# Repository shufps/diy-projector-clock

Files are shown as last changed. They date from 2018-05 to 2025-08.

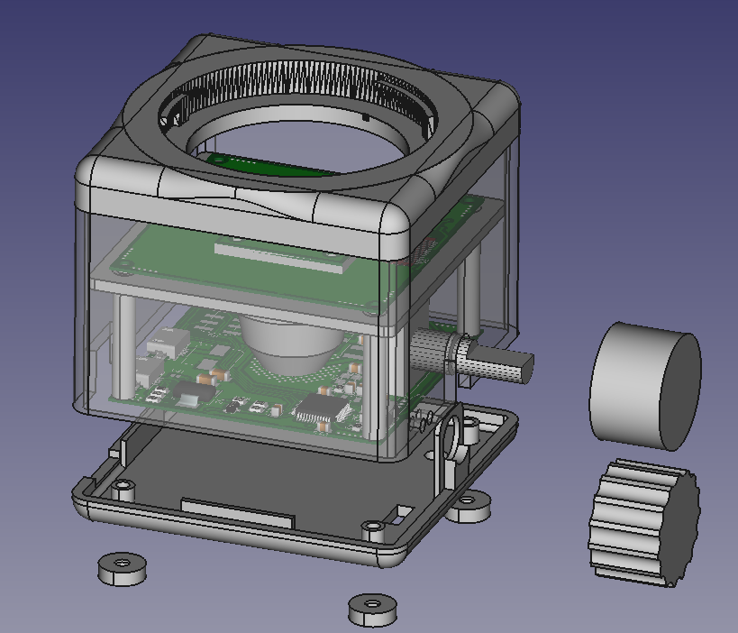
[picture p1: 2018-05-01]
images/Spectacle.Tw9321.png

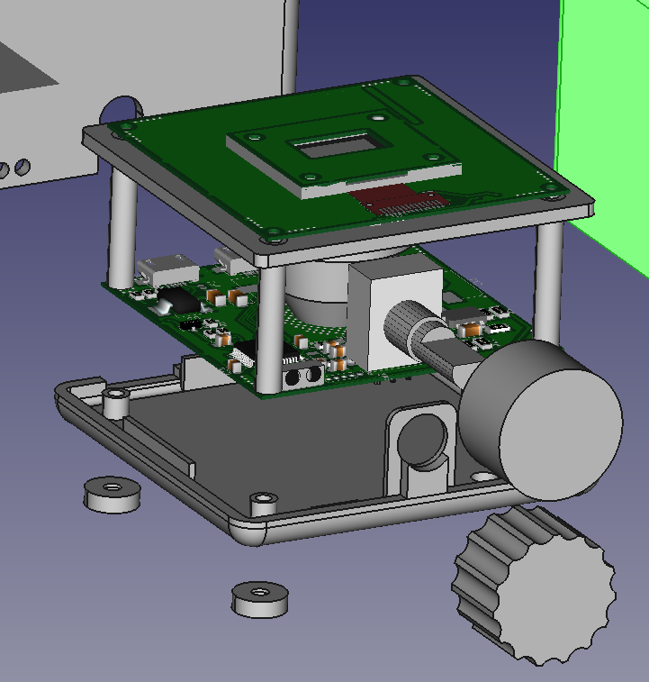
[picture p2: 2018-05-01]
stl/assembly.png

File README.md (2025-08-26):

# DIY Night Projector Clock

A Clock Projector can project the time to a ceiling in the night.



There are lots of commercial alarm clocks with integrated clock projector on the market but I thought, it would be fun to build one myself.

Moreover it was a good project for becoming accustomed to the process of 3d-designing cases which can be 3d printed and to learn about designing tolerances.

The principle is easy – basically it works like a video beamer (or any other projecting clock^^).



## LCD and Calculations
I choosed a small negative (background black) 64×32 LCD which has the dimensions of just 15mm x 12mm (active area 11.18mm x 5.58mm).



The goal was to build a complete projector with not more than 50mm x 50mm x 50mm (which I didn’t managed … But close to^^).

A small LCD has the advantage that everything becomes smaller and cheaper – this influences heavily costs for optics because a smaller LCD needs smaller optics to project an low distorted image.

Moreover a smaller LCD needs smaller focal length for a decent sized imaged on the ceiling. A good distance would be 2m from LCD to ceiling.

The formula for image width depending from the focal length is defined as:





with:
– S2 distance from lens to LCD and
– S1 distance from lens to ceiling
– W2 is the width of the LCD
– W1 is the width of the projected image

The formulas show that the smaller the focal length the larger the projected image will be.

I decided to go for 25mm because there are cheap lenses which can be obtained for about $12 in china.

For our values that would magnify the image by about x80 – 11.1mm LCD width would become 88.1cm image width on the ceiling in a distance of 2m.

## Light and Condensor Lens
It was not really clear how strong a LED has to be in order to get a reasonable well readable picture in the night on the ceiling.

To be sure – actually I wasn’t really – I decided to use a high power LED with 1W and use a cheap chinese condensor lense to parallelize the light before it passes the LCD (this has do be done anyway but a condensor lens makes it possible to use more light because condensors are shaped in a way that allowes to get the lens as near to the LED as possible – so catching more light).




The two pictures show the condensor-lense which is directly mounted to the PCB the resulting light spot on the ceiling. It is a really gread lens which is made for my LED – so it fits perfectly and parallelizes the light nicely.

## Electronics Construction
Two PCBs were designed – one holding the LCD and the actual projecting board.




The latter is equipped with 1W LED driver, STM32F103 Cortex ARM, a rotary encoder (for changing settings like brightness, standby-timer, time, …), USB, IR (both not used yet).

## Mechanics Construction
Originally, I aimed for 50mm x 50mm x 50mm but I only managed to get to 60mm x 60mm x 60mm 😥 😉

Here an overview about all I designed:



From left to right: Case with DIY projection lens (I skip this part – it worked but not really well), Sony E-Mount, C-Mount. In the middle the rest.

## LCD-Holder
A custom LCD-holder was designed to perfectly mount the LCD on the right place on the PCB.




## Case – C-Mount Variant
There are incredibly cheap chinase C-Mount lenses with a focal length of 25mm. They are sooo cheap that image quality is really really bad when using for fotography.



But surprisingly it works (almost) perfect for the Mini DIY Projector 😀



The pillow-effect (optical distortion where the edges are not straight but bent outwards) is almost neglectable – resulting a much better image than I expected (after reading reviews to this lense)



## Case – Sony E-Mount Variant
Just for fun – and because I have a 3d printer which works reliably without much attention – I did a variant for Sony E-Mount.



Here the projector with Walimex Pro 10mm 2.8 lens.



I have to admit – it isn’t that bright in reality but it’s still very readable although it is so large.



The image has more than 2m in width! And distortions almost non-existent 🙂

Downloads
GitHub-Repository contains:
– Schematic
– Layout
– Bill of material
– STM32 Cortex ARM Source
– 3D-STL-Files
– Images

Thingiverse: https://www.thingiverse.com/thing:2887852

Archive of original site: https://web.archive.org/web/20241128173803/https://microengineer.eu/2018/05/01/diy-night-clock-projector/

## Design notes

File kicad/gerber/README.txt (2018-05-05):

For best fitting, please make PCB with 0.5mm height.

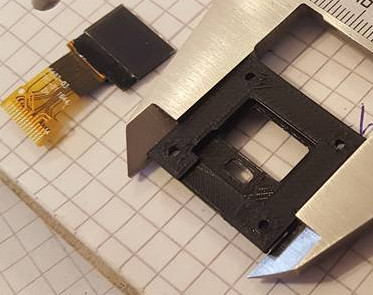
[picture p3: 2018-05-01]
images/22780314_1206666822799181_4845087505472371951_n.jpg

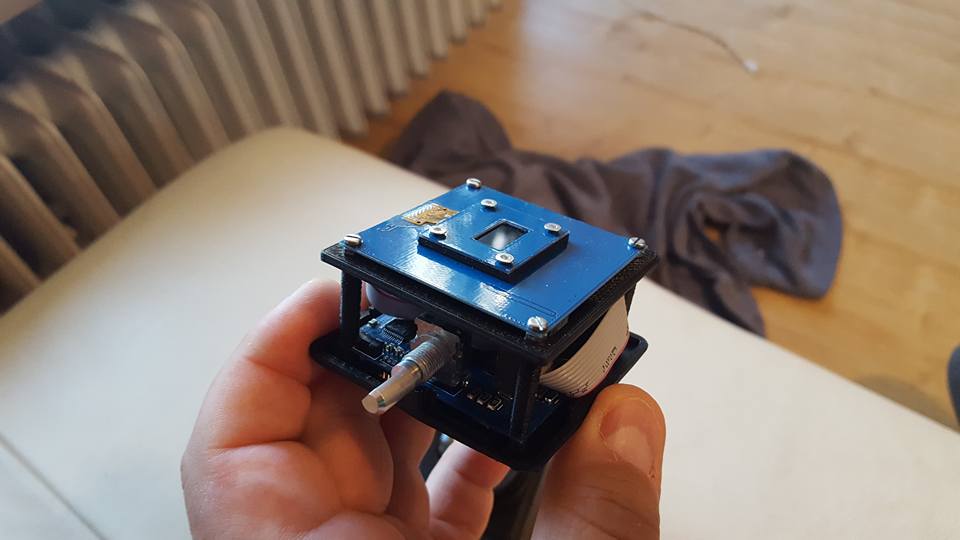
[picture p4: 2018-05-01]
images/23244059_1218023491663514_6128260922593770176_n.jpg

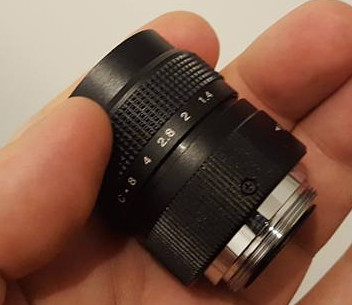
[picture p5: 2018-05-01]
images/23380257_1223416981124165_4793755427854490814_n.jpg

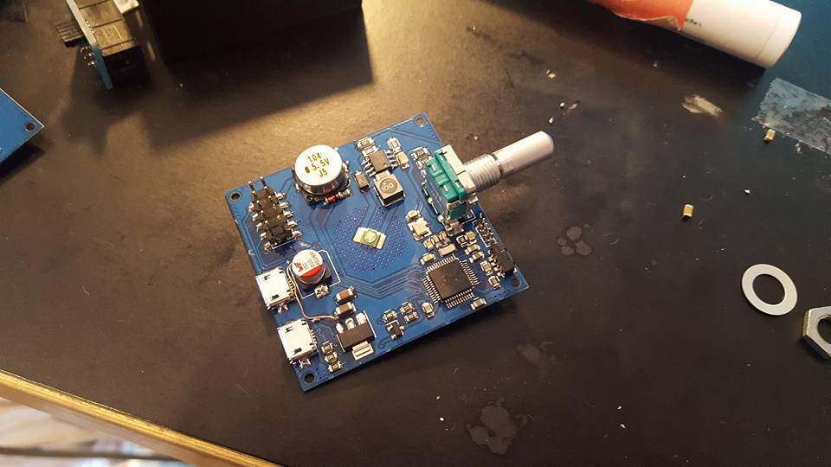
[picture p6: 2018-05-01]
images/22780624_1207215072744356_6448307703032848811_n.jpg

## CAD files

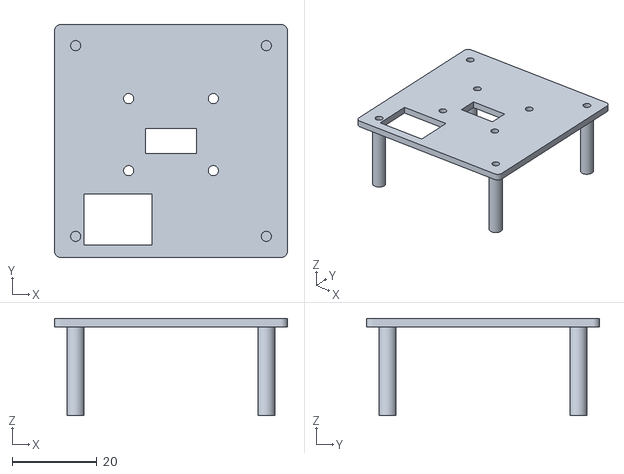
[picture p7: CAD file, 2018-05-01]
stl/spacer.stl
55.0 x 55.0 x 23.0

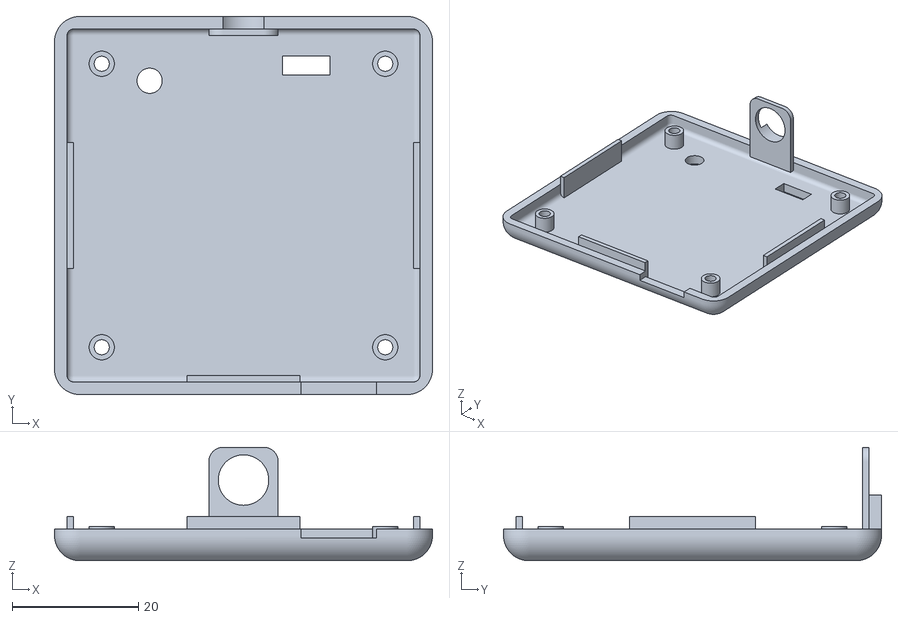
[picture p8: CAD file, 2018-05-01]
stl/case_bottom.stl
60.0 x 60.0 x 18.0

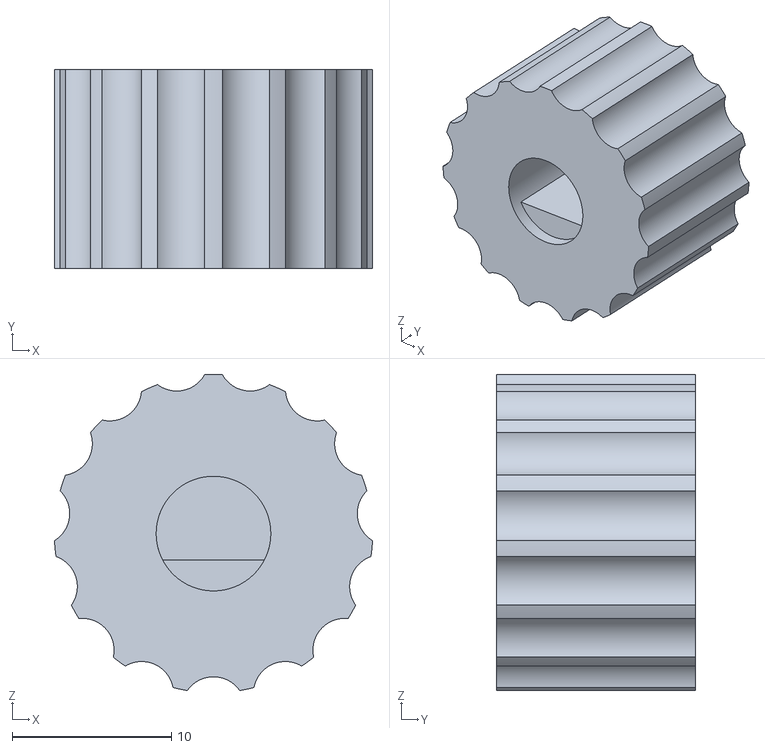
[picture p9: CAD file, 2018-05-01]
stl/know.stl
20.0 x 12.5 x 19.9

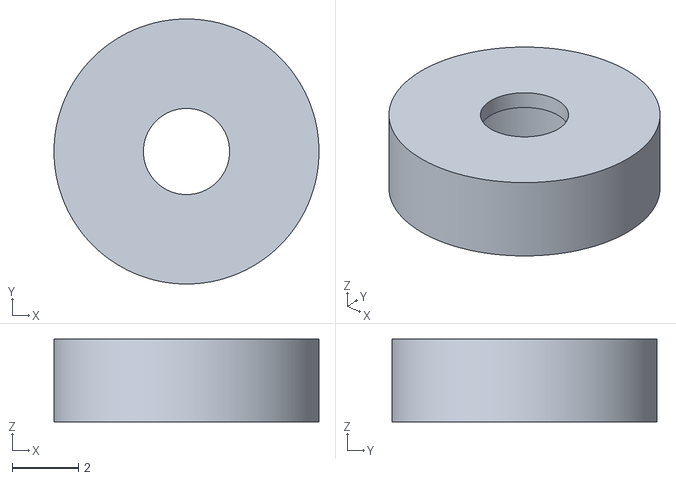
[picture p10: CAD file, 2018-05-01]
stl/case_foot.stl
8.00 x 8.00 x 2.50

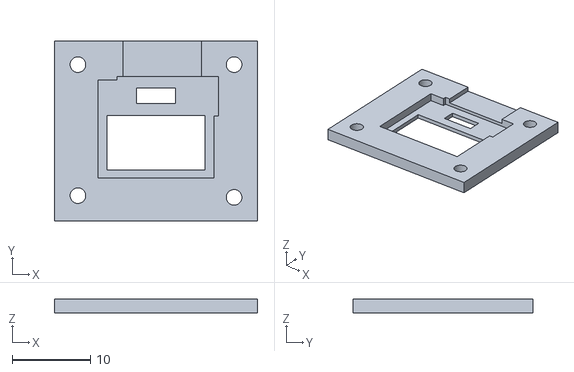
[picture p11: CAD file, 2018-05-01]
stl/lcd_holder.stl
26.0 x 23.0 x 1.80

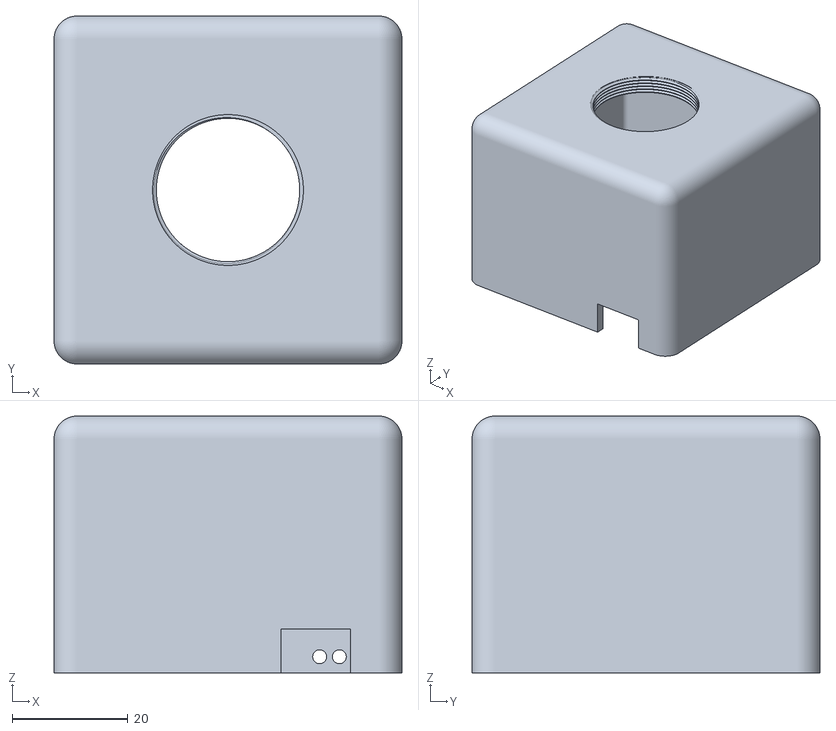
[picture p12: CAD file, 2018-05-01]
stl/case_top_cmount.stl
60.0 x 60.0 x 44.3

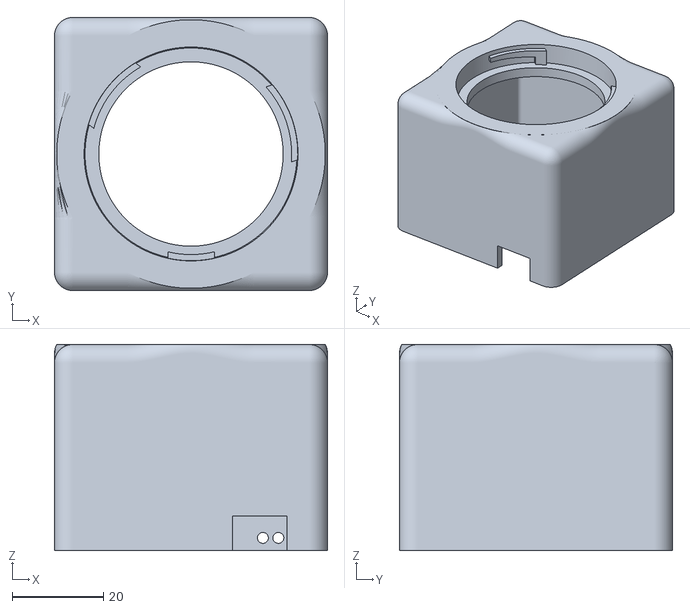
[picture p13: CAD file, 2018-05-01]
stl/case_top_emount.stl
60.0 x 60.0 x 45.3

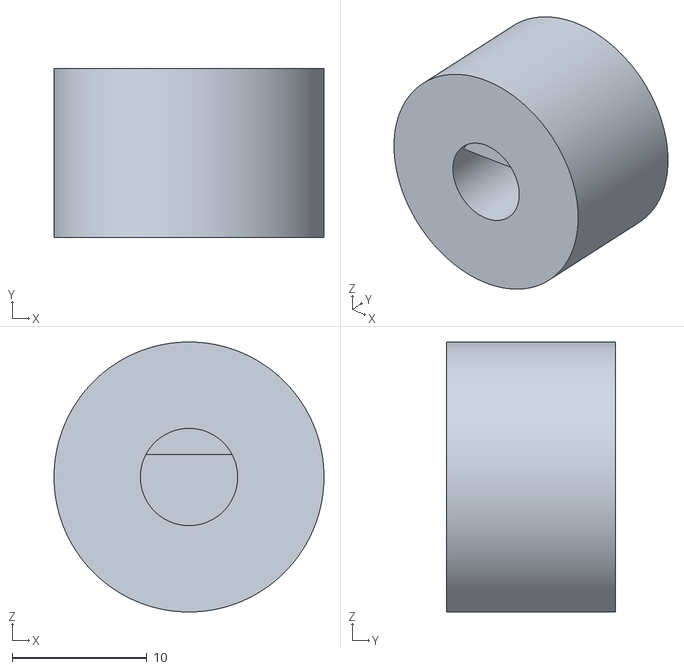
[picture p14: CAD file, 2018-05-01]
stl/knob_smooth.stl
20.0 x 12.5 x 20.0

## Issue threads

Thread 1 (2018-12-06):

Which LCD ?

spilz87, 2018-12-06:
Hello,
Very nice project, I was thinking about it for years but I didn’t find how to find the lcd.
Where did you buy the lcd ?
What’s it with backlight led that you removed ?
Thanks for your project
Regards

shufps, 2018-12-10:
Hi, sorry for answering so late ... In the repo there is a directory called "BOM" (bill of material) and in the text-file "others" there is the LCD which works:

LCD:
(search on ebay for LCD 64x32) e.g.
GLS Neu LCD-VATN 64x32 3V ST7567A I2C 15x12x2mm [LCD-AG-064032V-VIW W/KKK-E6]

shufps, 2018-12-10:
Ah forgot to answer the other question - you simply can remove without much force the backlight from the LCD :)

spilz87, 2018-12-10:
Thanks for your replies :)
I didn’t see the BOM folder ...
But there is no link to buy it.
Is there a difference with another classic RGB lcd ? (Except the size maybe)
I didn’t find your lcd on AliExpress, but I found this one :

https://www.google.fr/amp/s/m.aliexpress.com/item/32859445140.html#ampf=undefined

If I use it as “black/white” do you know if it will work or not ?
Thanks for your help

shufps, 2018-12-12:
No, OLEDs can't be used for projectors in general.

Buy this:
https://www.ebay.de/itm/GLS-Neu-LCD-VATN-64x32-3V-ST7567A-I2C-15x12x2mm-LCD-AG-064032V-VIW-W-KKK-E6/391734506852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

shufps, 2018-12-12:
Ah sorry, you are right ... Just read "OLED" at the end of the title and missed the "not" before xD
You can try, but you will have to change everything ... This would be a lot of work and would be very time consuming. If you do, I would like to keep updated, if you don't mind :)

But I don't know how good the contrast will be ... perhaps black background is milky then. This small little LCD seems to have been build for projecting applications - but of course we don't know for real.

spilz87, 2018-12-12:
The contrast could be the issue with this RGB lcd, that why I’m thinking using it only in white/black, hopping it will be enough ...

Your small lcd seems to be design to feet in key :
Q5-100-STARTER-KIT 64x32 Spi Lcd Switch & Breakout Board https://rover.ebay.com/rover/0/0/0?mpre=https%3A%2F%2Fwww.ebay.com%2Fulk%2Fitm%2F132276707938

The electronic hardware shouldn’t be a problem, I’m thinking using an ESP32 to control display, get time through internet and maybe to project small icon of weather :)

My real issue in my project was what you solved : the optical hardware

I will let you know when I will receive the components and share with you my knowledge and my project if you want

I will maybe have more questions ^^

shufps, 2018-12-12:
Niiiiice! Thank you for the link! That could be the reason why this LCD exists :-)

Looking forward hearing about your progress! :-)

spilz87, 2019-04-18:
Hello,
I’m working a lot on this project and it start to work well.
Until now I’m using the LCD 160x80 in SPI.
But I would like to have it brighter so I will test the same LCD as you.
Can you tel me more about the connection of this LCD :
Which pin of the LCD did you connect to 3.3v ? (On there are pins for dc/dc converter and one for 3.0v)
Why did you keep the led pin ?
Thanks for your help

I don’t know how to send photo of my project

shufps, 2019-04-18:
Hello,

ah yes, why did I keep the Pin for the backlight - I don't know to be honest ... The back light is removed anyways xD

I connected Pin 8 to 3.3V. You can open the schematic with KiCad.

Pilgrim182521, 2019-10-11:
Hi guys,
just started looking for LCD glass and found something like this in EU:
https://allegro.pl/oferta/art-lcd-vatn-64x32-3v-st7567a-i2c-15x12x2mm-whiten-6754828746
for some 3 Euros, shipping  included.
josef

trizmark, 2020-03-19:
Hey @shufps

Do you have a recent link to an LCD display? This is an awesome project and I'm finding it hard to locate a suitable LCD.

Thanks,
Zoltan

Pilgrim182521, 2020-03-19:
https://allegro.pl/oferta/art-lcd-vatn-64x32-3v-st7567a-i2c-15x12x2mm-whiten-6754828746
is still valid...
Josef

Pilgrim182521, 2020-03-19:
... whoops sorry, it has not been query for me... ;)

trizmark, 2020-03-19:
> ... whoops sorry, it has not been query for me... ;)

I had a look at that, but due to the current COVID-19 situation that website have stopped delivering to non-Polish addresses... :(

Appreciate the reply anyway!

AmbroAnalog, 2020-10-21:
The store Allegro.pl now seems to deliver outside Poland again, I received my shipment to Germany today.

How exactly do I get the display transparent to show through with the LED? Do I have to remove the black layer at the back?

Cthanatos, 2021-08-12:
Any chance you could provide an aliexpress link? I've tried the link above and it's in Polish, and Google's translate page feature isn't great. I've tried searching  the line from the BOM, even parts of the line but I can't seem to find what I'm looking for....

jghaanstra, 2022-01-18:
Anyone ever found a suitable replacement for the led screen in the project? I tried ordering through the Polish webshop but there is an issue with delivery and I probably lost my money. I have been unsuccesful finding a replacement.

spilz87, 2022-01-18:
If you are able to change the library you can take any lcd screen.
I'm using 0.96in tft display 80x160 with arduino based electronics and it works well

spilz87, 2022-01-18:
€ 1,69  11％ Off | 2022 New 0.96in TFT Display Module IPS Color Screen SPI For LCD 80x160 ST7735 Drive Welded Spliced Link
https://a.aliexpress.com/_vMIfpr

trizmark, 2022-01-18:
But that's not a negative LCD, right? So how would you use that for projection?

spilz87, 2022-01-18:
You have to remove the backlight

jghaanstra, 2022-01-18:
Actually just bought me the black version of [this ](https://nl.aliexpress.com/item/4000370015852.html?gatewayAdapt=glo2nld&spm=a2g0o.9042311.0.0.49714c4dHxym9T) one to try out. It comes without the backlight.

jghaanstra, 2022-01-18:
> Thanks for the link, I didn't saw it
>
> But the density of pixel is not as good, and the issue I didn't solved is a way to have an homogeneous light before the lcd screen

I assume you mean the light behind the LCD screen? Did you use some form of condensor to try and get an homogeneous light?

spilz87, 2022-01-18:
Yes the light behind the lcd screen

I tried several things but I always have something not homogeneous :(

What do you use for it ?

jghaanstra, 2022-01-18:
I just started looking into all this and I have no experience with these kind of projects. But I bought [this ](https://www.aliexpress.com/item/1W-3W-Constant-Current-LED-Driver-Warm-Natural-Cool-White-Blue-Red-Green-Yellow-LED-Chip/32984506965.html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) one as a first attempt. And I thought I just reflective tape or aluminum foil for extra spread.

spilz87, 2022-01-18:
The link does not work for me

zoltan-vonage, 2022-01-18:
> You have to remove the backlight

How hard is it to remove the backlight?

trizmark, 2022-01-18:
> You have to remove the backlight

How hard is it to remove the backlight?

jghaanstra, 2022-01-18:
> The link does not work for me

Does [this ](https://aliexpress.com/item/32984506965.html) work?

spilz87, 2022-01-18:
Yes the link works

I already tried this but it's not homogeneous and you saw it on the wall

jghaanstra, 2022-01-18:
> Yes the link works
>
> I already tried this but it's not homogeneous and you saw it on the wall

OK. what gave you the best results?

spilz87, 2022-01-18:
The best I found was a led with this :

€ 0,98 | Cree XPG lens Diameter 23.5mm (Belt holder) 5 degrees LED Lens, glass Condenser lens,
https://a.aliexpress.com/_vl5RYv

But not perfect

And as the screen is bigger, you see halo on the wall :(

catalin7, 2025-08-07:
i did my clcocprojector from a laying around clock projector. I hacked the communication to the lcd's driver with a logic analyzer, in a day i had my communication protocol established and for fun actually i have 4 display projectors , i use only 1 , my bestie. Some clocks dont have lcd driver, the lcd is connected tru a plastic conductive ribbon to the lcd. These are not good.
So my clocks are one from an Accurite, 2 from a Mesqool CR1001 i think, and another one from a LaCrosse not working clock

catalin7, 2025-08-07:
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

spilz87, 2025-08-07:
Thanks for sharing
I worked also on it and I was able to create my own one from classic lcd (no oled) by removing some back parts (not that easy, I broke some 😅)

The most difficult part is to find an homogenized light source..

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

spilz87, 2025-08-07:
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

catalin7, 2025-08-08:
or make smaller characters on a black background screen

catalin7, 2025-08-08:
this is one of my projects, it uses a projector from a clock ceiling

Closed 2018-12-10.

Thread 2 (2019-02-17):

projecting board?

jasondreher, 2019-02-17:
I can’t seem to find the board with the light on it, the project board. What did you use for this? And I assume this connects to the screen and gives it the time. I want to use this for a kitchen timer, display a countdown on the wall.

Great project, I am looking forward to trying it out!

shufps, 2019-02-28:
great idea! love it :) All board files are in the directory "kicad". The board file is named "beamer1.kicad_pcb".

Closed 2019-12-18.

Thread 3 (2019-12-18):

Clock doesn't reset to 0:00 after 23:59. It keeps counting the hours to 24, 25, 26...

SmallestLeslie, 2019-12-18:
I would like to ask for your help.
I'm trying to build the projector clock project I found here as a Chirstmas gift for my brother and I encountered some strange behavior with the firmware.
When it is in the time adjust mode it works as it should but during normal operation mode after 23:59 the date doesn't increment and the clock doesn't turn over to 0:00.
Rather it keeps incrementing the hours to 24, 25 and so on.

I would like to ask if you encountered a similar behavior and if you
have an updated firmware.

shufps, 2019-12-18:
Oh, interesting observation! :see_no_evil:

Have to admit - my girlfriend didn't want me to use the projector-clock in the bed-room, so it didn't ever run so long :/

Hmm, oh that is this silly STM32F103 microcontroller ... it really doesn't care about overflows at 24:00.

Could you retry by changing this line:
https://github.com/shufps/diy-projector-clock/blob/master/src/src/main.cpp#L233

from:
rtc_getTime24(&RTC_TimeStructure);
rtc_getDate(&RTC_DateStructure);

to:
rtc_checkUpdateDate(&RTC_TimeStructure, &RTC_DateStructure);
rtc_getTime24(&RTC_TimeStructure);
rtc_getDate(&RTC_DateStructure);

The checkUpdateDate-function also is used when reconnecting the main-power while the RTC run on battery-backup. The seconds count continuosly up. When reconnecting the clock to the main-power it has to figure out how many days have passed and it adjusts the date accordingly by calling this function.

The same has to be done for the clock not running on battery. After the RTC-counter reaches 86400 seconds, it has to be reset and the date has to be adjusted.

I hope this solves your issues :)

Btw, I would looooooove seeing a picture of your clock :heart_eyes:

shufps, 2019-12-18:
You can use the binary from this branch which has the fix:
https://github.com/shufps/diy-projector-clock/tree/24hoursbug

If it works, I'll merge into the master-branch :)

SmallestLeslie, 2019-12-18:
Unfortunately I haven't been able to compile even the original source due to the lack of unistd.h in my system (windows).
I would be happy if you could compile it for me.
Am I correct that you did compile on linux?

Oh, and one more question.
In the rtc_checkUpdateDate is the "switch (date->RTC_Date)" correct?
Shouldn't it be RTC_Month?

SmallestLeslie, 2019-12-18:
Thank you very much for the binary!
I will try it tonight.

shufps, 2019-12-18:
Oh yes, you are right!
I changed it and updated the branch :)

Yes, I'm using Linux - never tried Windows, sorry :thinking: :man_shrugging:

SmallestLeslie, 2019-12-18:
I haven't made a casing for it but I want to do it in the following days. Then I will post a picture I promise.

> never tried Windows, sorry
I shouldn't have either :)

Thank you for your help!
You saved me.

SmallestLeslie, 2019-12-19:
I burned the modified FW into the MCU last night and it works now.
Thank you very much.

If it is possible I would like to ask you for a small modification.
Could you please change the names of the days as the following?
Monday = H
Tuesday = K
Wednesday = Sze
Thursday = Cs
Friday = P
Saturday = Szo
Sunday = V

If I'm correct the line "char dayNames[][12] = { "Mo", "Di", "Mi", "Do", "Fr", "Sa", "So" };"
should be modified in the main.cpp to "char dayNames[][12] = { "H", "K", "Sze", "Cs", "P", "Szo", "V" };".

Unfortunately in our language it is not common to use abbreviations of names of the days with uniform length and furthermore there are special characters like: é á ö ő ü.
It is fine for now if the text is not aligned dynamically. I will take care of it once I'm able to setup a working toolchain.

Thank you once more!

shufps, 2019-12-20:
Try this one: https://github.com/shufps/diy-projector-clock/tree/altweekdaynames

I tried to center the text - but couldn't test it :man_shrugging:

SmallestLeslie, 2019-12-24:
It works and it is perfect!
Finally I finished the casing.
I am inexperienced so I messed up multiple times but at the end it seems I was able to finish it.
I don't have a 3d printer so I made the casing out of 3 and 5 mm thick ABS plastic sheets and then glued and screwed together. I bought a lens for this project but it turned out to be useless so I had to improvise. The box should be lower but I made it based on a wrong version of the drawings.
The clock still needs a better fitting knob.
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

shufps, 2019-12-25:
wow gratulation! love it :heart:

Closed 2019-12-24.

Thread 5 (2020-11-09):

Transfer STM32 program

AmbroAnalog, 2020-11-09:
First of all many thanks for your great project!
I have assembled the boards so far.

Now I am at the point where I want to transfer your software via my ST-Link V2 to the STM32.

Which files from the _src_ folder do I need and which program would you recommend?

shufps, 2020-11-13:
Hi, you could try it with openocd like
```
openocd -f myboard.cfg -c "program ./Release/beamer1.bin exit 0x08000000"
```

I added the binary file to the repository. The `myboard.cfg` is in the src-directory, the binary is in `src/Release`.

If this doesn't work, you could use other tools like `st-flash` (I think if I remember correctly). There should be plenty of tools to write a .hex or .bin to a stm32f103 with a STLinkV2.

Good luck :)

Closed 2020-11-13.

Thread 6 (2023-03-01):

How far the C-Mount lenses should be from the LCD ?

IgorTrud, 2023-03-01:
How far the C-Mount lenses should be from the LCD ?
What tolerance is acceptable ?
(or I have a misunderstanding  - this not a focus point, and could be tunned on lens rotary itself ?)

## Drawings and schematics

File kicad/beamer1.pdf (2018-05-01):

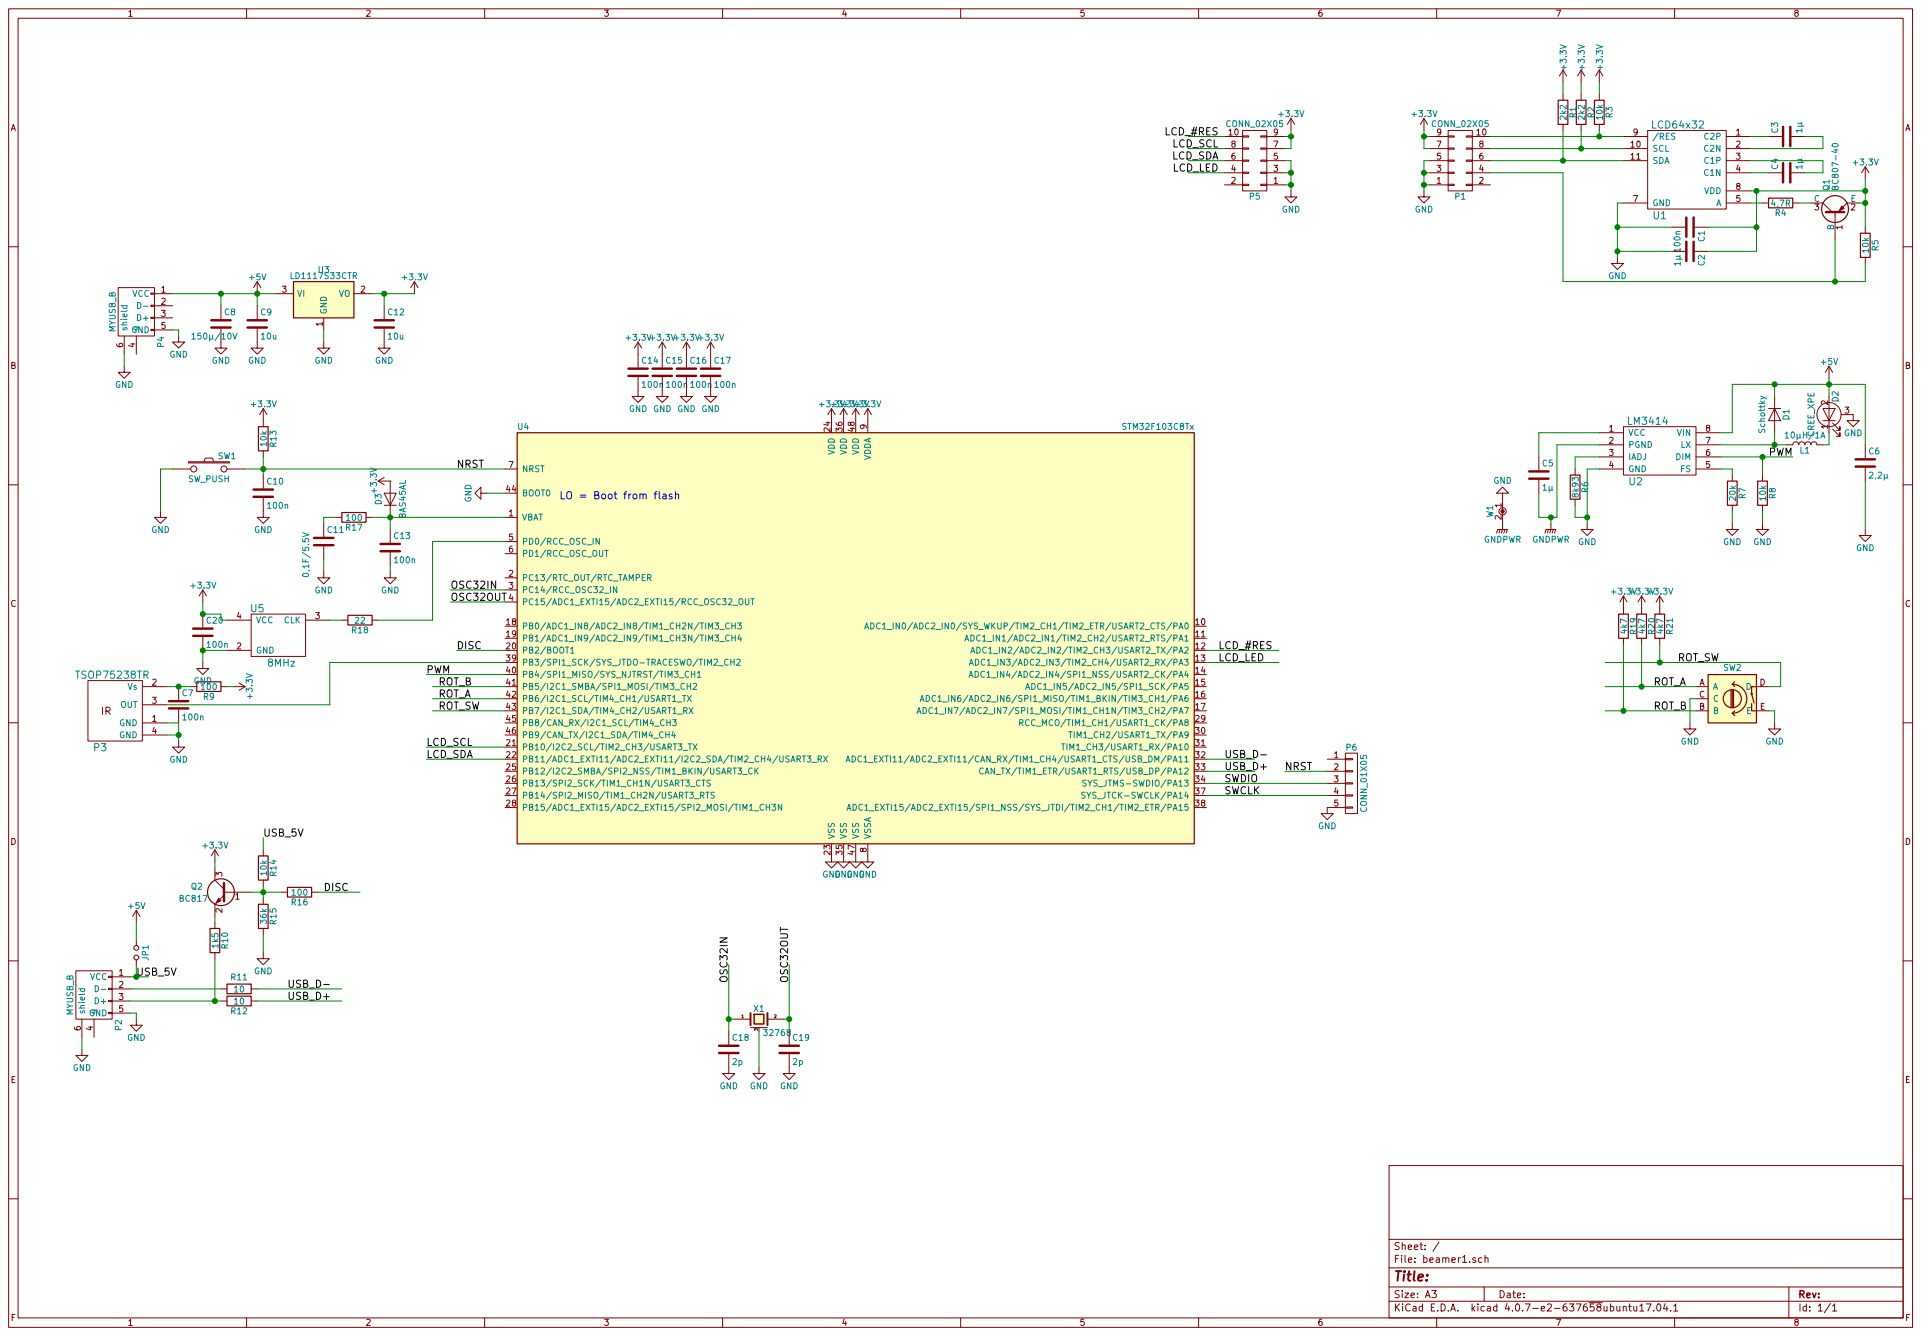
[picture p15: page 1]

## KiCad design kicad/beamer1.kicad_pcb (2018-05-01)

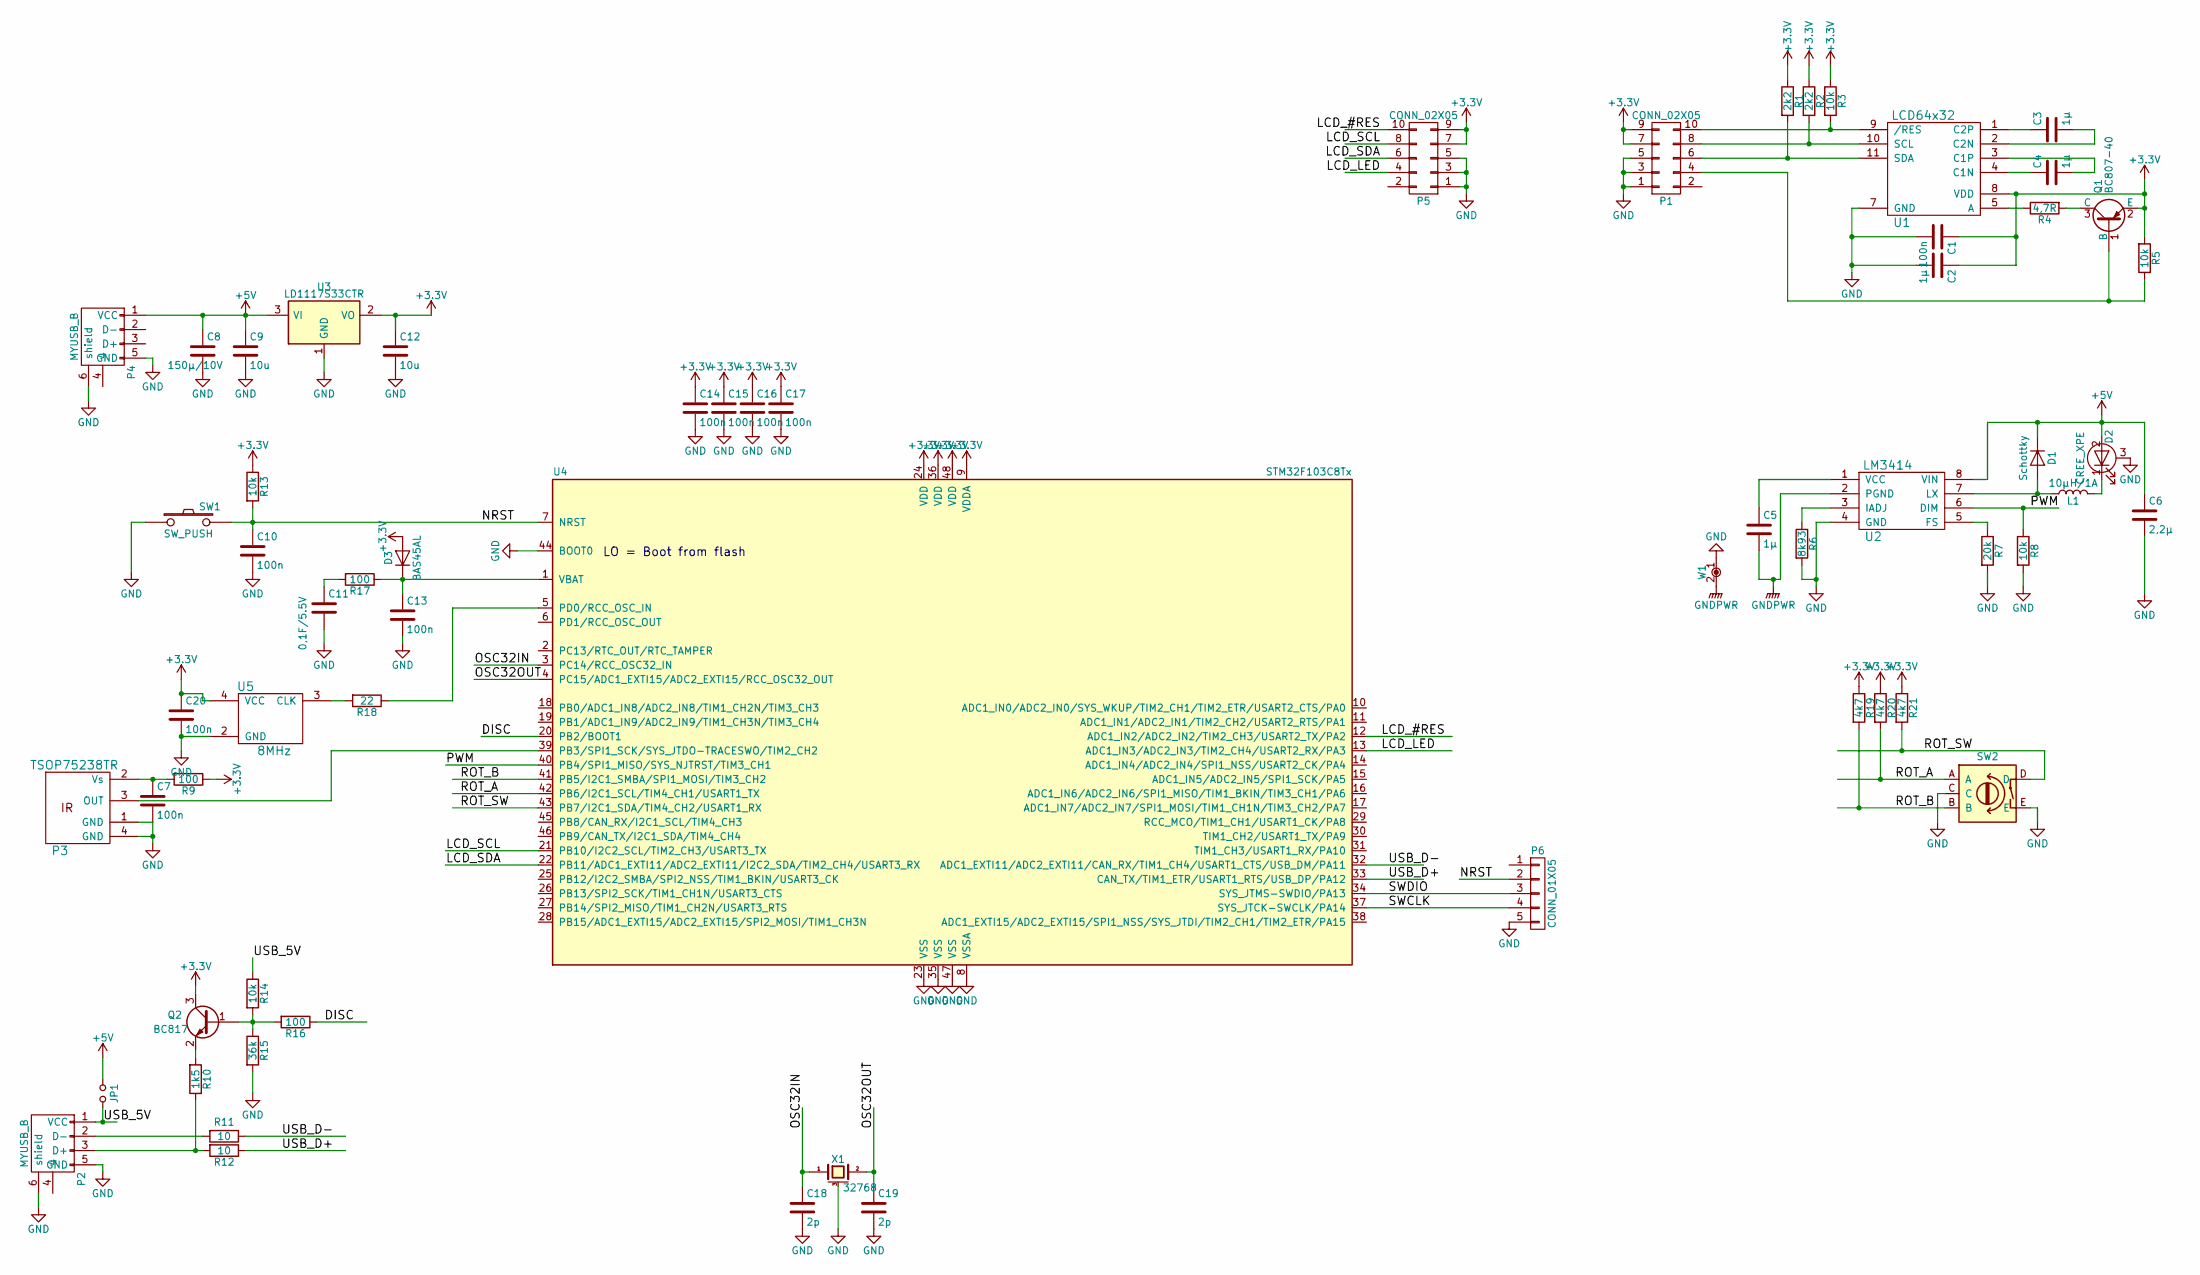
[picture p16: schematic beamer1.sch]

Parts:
C1: 100n; C_1206
C2, C3, C4, C5: 1µ; C_1206
C6: 2,2µ; C_1206
C7, C10, C13, C14, C15, C16, C17, C20: 100n; C_0805
C8: 150µ/10V; CP_Elec_8x6.7
C9, C12: 10u; C_1206
C11: 0,1F/5.5V; CP_Elec_10x7.7
C18, C19: 2p; C_0805
D1: Schottky; D_MiniMELF
D2: CREE_XPE; CREE_XLAMP_XP-E
D3: BAS45AL; D_0805
JP1: Jumper_NO_Small; SOLDERJMP
L1: 10µH/1A; Inductor_Taiyo-Yuden_NR-50xx
P1, P5: CONN_02X05; Pin_Header_Straight_2x05_Pitch2.54mm_SMD
P2, P4: MYUSB_B; MICROUSBB
P3: TSOP75238TR; TSOP752
P6: CONN_01X05; Pin_Header_Straight_1x05_Pitch1.27mm
Q1: BC807-40; SOT-23
Q2: BC817; SOT-23
R1, R2: 2k2; R_1206
R3, R5, R8: 10k; R_1206
R4: 4,7R; R_1210
R6: 8k93; R_1206
R7: 20k; R_1206
R9, R16, R17: 100; R_0805
R10: 1k5; R_0805
R11, R12: 10; R_0805
R13, R14: 10k; R_0805
R15: 36k; R_0805
R18: 22; R_0805
R19, R20, R21: 4k7; R_1206
SW1: SW_PUSH; KURZHUB_SMD
SW2: Rotary_Encoder_Switch_My; EC11B_ROTARY
U1: LCD64x32
U2: LM3414; SOIC-8-N
U3: LD1117S33CTR; SOT-223-3Lead_TabPin2
U4: STM32F103C8Tx; LQFP-48_7x7mm_Pitch0.5mm
U5: 8MHz; SMDOSZIL
W1: NET-TIE; NET-TIE-0.3mm
X1: 32768; Crystal_SMD_3215-2pin_3.2x1.5mm

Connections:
+3V3: C1.1, C2.1, C12.1, C14.1, C15.1, C16.1, C17.1, C20.1, D3.2 (A), P1.7, P1.9, P5.7, P5.9, Q1.2 (E), Q2.3 (C), R1.1, R2.1, R3.1, R5.2, R9.1, R13.1, R19.1, R20.1, R21.1, U1.8 (VDD), U3.2 (VO), U4.9 (VDDA), U4.24 (VDD), U4.36 (VDD), U4.48 (VDD), U5.4 (VCC)
+5V: C6.1, C8.1, C9.1, D1.1 (K), D2.2 (A), JP1.1, P4.1 (VCC), U2.8 (VIN), U3.3 (VI)
/DISC: R16.1, U4.20 (PB2/BOOT1)
/LCD_#RES: P5.10, U4.12 (ADC1_IN2/ADC2_IN2/TIM2_CH3/USART2_TX/PA2)
/LCD_LED: P5.4, U4.13 (ADC1_IN3/ADC2_IN3/TIM2_CH4/USART2_RX/PA3)
/LCD_SCL: P5.8, U4.21 (PB10/I2C2_SCL/TIM2_CH3/USART3_TX)
/LCD_SDA: P5.6, U4.22 (PB11/ADC1_EXTI11/ADC2_EXTI11/I2C2_SDA/T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)
/NRST: C10.1, P6.2, R13.2, SW1.2, U4.7 (NRST)
/OSC32IN: C18.1, U4.3 (PC14/RCC_OSC32_IN), X1.1
/OSC32OUT: C19.1, U4.4 (PC15/ADC1_EXTI15/ADC2_EXTI15/RCC_OSC32_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), X1.2
/PWM: R8.1, U2.6 (DIM), U4.40 (PB4/SPI1_MISO/SYS_NJTRST/TIM3_CH1)
/ROT_A: R20.2, SW2.A, U4.42 (PB6/I2C1_SCL/TIM4_CH1/USART1_TX)
/ROT_B: R19.2, SW2.B, U4.41 (PB5/I2C1_SMBA/SPI1_MOSI/TIM3_CH2)
/ROT_SW: R21.2, SW2.D, U4.43 (PB7/I2C1_SDA/TIM4_CH2/USART1_RX)
/SWCLK: P6.4, U4.37 (SYS_JTCK-SWCLK/PA14)
/SWDIO: P6.3, U4.34 (SYS_JTMS-SWDIO/PA13)
/USB_5V: JP1.2, P2.1 (VCC), R14.1
/USB_D+: R12.1, U4.33 (CAN_TX/TIM1_ETR/USART1_RTS/USB_DP/PA12)
/USB_D-: R11.1, U4.32 (ADC1_EXTI11/ADC2_EXTI11/CAN_RX/TIM1_CH4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)
GND: C1.2, C2.2, C6.2, C7.2, C8.2, C9.2, C10.2, C11.2, C12.2, C13.2, C14.2, C15.2, C16.2, C17.2, C18.2, C19.2, C20.2, D2.3 (TERM), P1.1, P1.3, P1.5, P2.5 (GND), P2.6 (shield), P3.1 (GND), P3.4 (GND), P4.5 (GND), P4.6 (shield), P5.1, P5.3, P5.5, P6.5, R6.2, R7.2, R8.2, R15.2, SW1.1, SW2.C, SW2.E, U1.7 (GND), U2.4 (GND), U3.1 (GND), U4.8 (VSSA), U4.23 (VSS), U4.35 (VSS), U4.44 (BOOT0), U4.47 (VSS), U5.2 (GND), W1.1, X1.3 (case)
GNDPWR: C5.2, U2.2 (PGND), W1.2
unnamed: C3.1, U1.1 (C2P)
unnamed: C3.2, U1.2 (C2N)
unnamed: C4.1, U1.4 (C1N)
unnamed: C4.2, U1.3 (C1P)
unnamed: C5.1, U2.1 (VCC)
unnamed: C7.1, P3.2 (Vs), R9.2
unnamed: C11.1, R17.2
unnamed: C13.1, D3.1 (K), R17.1, U4.1 (VBAT)
unnamed: D1.2 (A), L1.1, U2.7 (LX)
unnamed: D2.1 (K), L1.2
unnamed: P1.4, Q1.1 (B), R5.1
unnamed: P1.6, R1.2, U1.11 (SDA)
unnamed: P1.8, R2.2, U1.10 (SCL)
unnamed: P1.10, R3.2, U1.9 (/RES)
unnamed: P2.2 (D-), R11.2
unnamed: P2.3 (D+), R10.1, R12.2
unnamed: P3.3 (OUT), U4.39 (PB3/SPI1_SCK/SYS_JTDO-TRACESWO/TIM2_CH2)
unnamed: Q1.3 (C), R4.2
unnamed: Q2.1 (B), R14.2, R15.1, R16.2
unnamed: Q2.2 (E), R10.2
unnamed: R4.1, U1.5 (A)
unnamed: R6.1, U2.3 (IADJ)
unnamed: R7.1, U2.5 (FS)
unnamed: R18.1, U4.5 (PD0/RCC_OSC_IN)
unnamed: R18.2, U5.3 (CLK)

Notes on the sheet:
LO = Boot from flash

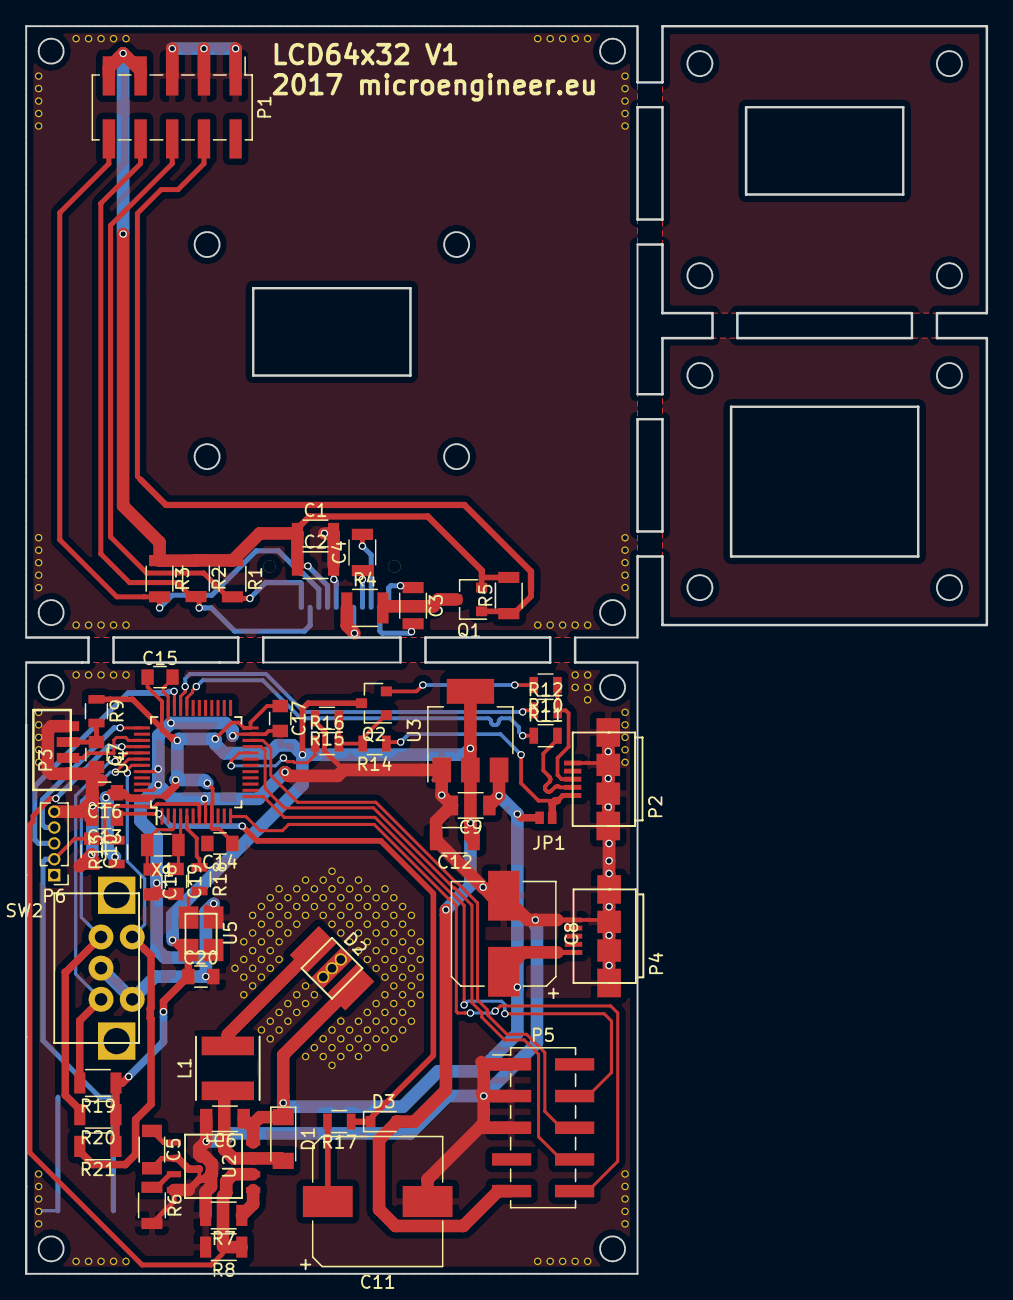
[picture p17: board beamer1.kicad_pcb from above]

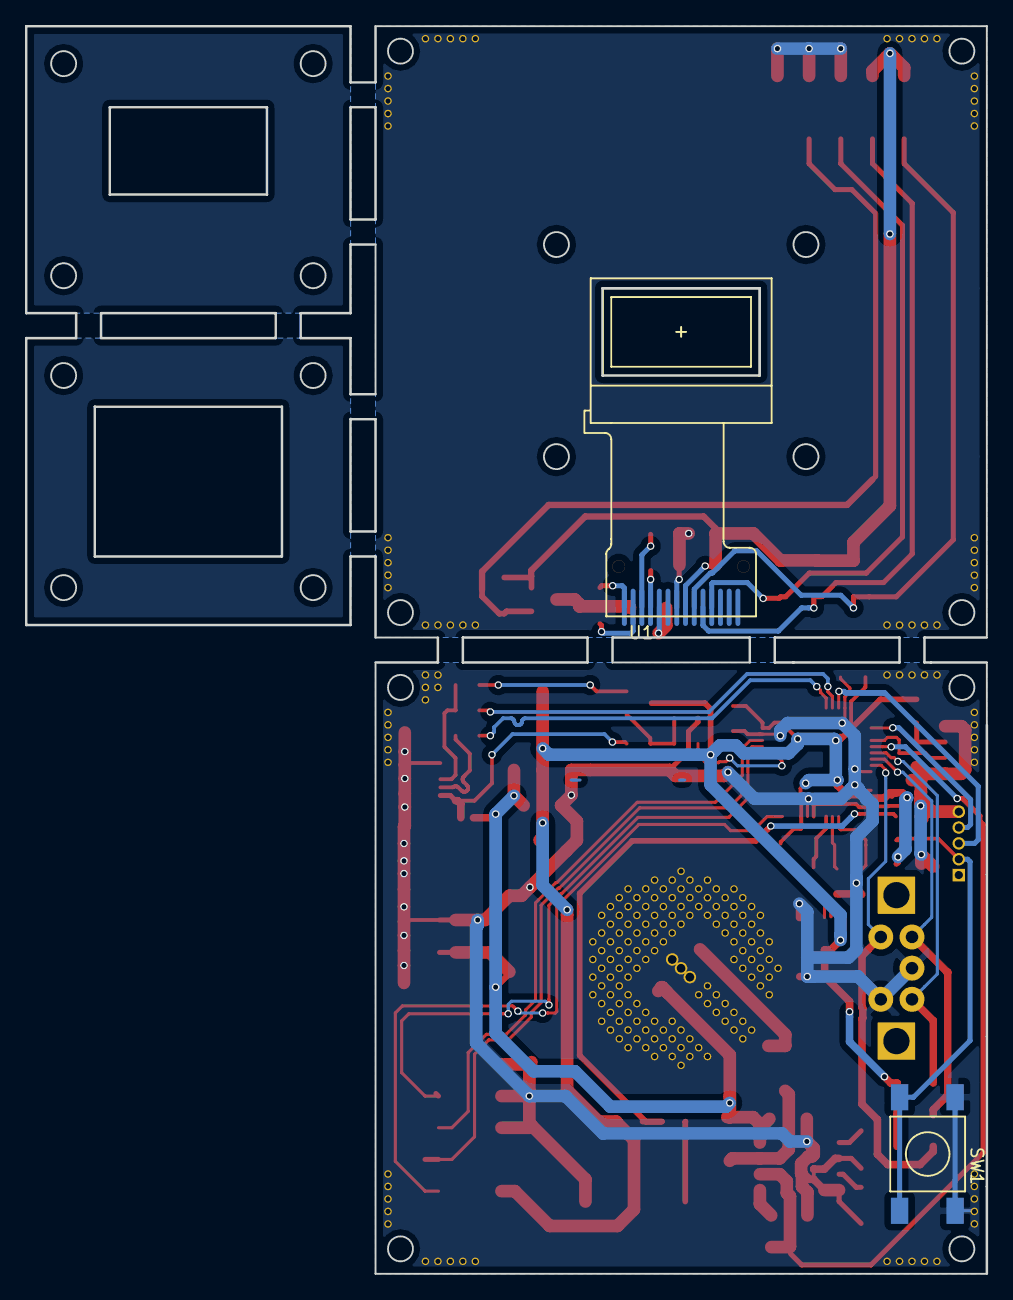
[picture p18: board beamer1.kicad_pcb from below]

Board: 2 copper layers, 77.0 x 100.0 mm, 63 parts (2 on the bottom side), 46 nets.

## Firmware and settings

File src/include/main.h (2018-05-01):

/**
 ******************************************************************************
 * File Name          : main.h
 * Description        : This file contains the common defines of the application
 ******************************************************************************
 *
 * Copyright (c) 2017 STMicroelectronics International N.V.
 * All rights reserved.
 *
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
 ******************************************************************************
 */
/* Define to prevent recursive inclusion -------------------------------------*/
#ifndef __MAIN_H
#define __MAIN_H

#include <inttypes.h>
#include "stm32f10x.h"
#include "stm32f10x_rtc.h"
//#include "stm32f1xx_hal_dma.h"
#include "stm32f10x_tim.h"

#ifndef min
#define min(a,b)	((a<b)?a:b)
#endif

#define DEFAULT_PWM 1023
#define DEFAULT_CONTRAST 40

#define GPIO_DISC		GPIOB,GPIO_Pin_2
#define GPIO_LCD_RESET 	GPIOA,GPIO_Pin_2


#define GPIO_PHASEA		GPIOB,GPIO_Pin_6
#define GPIO_PHASEB		GPIOB,GPIO_Pin_5
#define GPIO_SWITCH		GPIOB,GPIO_Pin_7
#define LUTPWMSIZE	1024



#endif /* __MAIN_H */
/************************ (C) COPYRIGHT STMicroelectronics *****END OF FILE****/

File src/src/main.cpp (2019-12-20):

/* 
 * This file is part of DIY-Projector-Clock
 * www.microengineer.eu
 * 
 * If you like my work, please consider to donate IOTAs to:
 * LLEYMHRKXWSPMGCMZFPKKTHSEMYJTNAZXSAYZGQUEXLXEEWPXUNWBFDWESOJVLHQHXOPQEYXGIRBYTLRWHMJAOSHUY
 *
 *
 * 
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
 * You should have received a copy of the GNU General Public License 
 * along with this program. If not, see <http://www.gnu.org/licenses/>.
 */

#include <stdio.h>
#include <stdlib.h>
#include <math.h>
#include <string.h>
#include <stdarg.h>
#include "diag/Trace.h"

#include "Timer.h"

#include "gpio.h"
#include "tim.h"
#include "i2c.h"
#include "lcd64x32.h"
#include "rtc.h"

#include "usb.h"

#include "ugui.h"
#include "ugui_config.h"
#include "icons.h"

#include "json.h"
#include "irmp.h"
#include "ir.h"
#include "rotenc.h"

extern const UG_FONT FONT_12X16;
//extern const UG_FONT FONT_6X10;

const UG_FONT* font = &FONT_12X16;
//const UG_FONT* fonts = &FONT_6X10;

static UG_GUI gui;

#define ADJUST_NOP	0
#define ADJUST_BRIGHTNESS 1
#define ADJUST_CONTRAST 2
#define ADJUST_TIME	3
#define ADJUST_DATE 4
#define ADJUST_ICON 5
#define ADJUST_TIMER 6

#define DISPLAY_TIME	0
#define DISPLAY_ICON	1
#define DISPLAY_ADJ_TIMEDATE	2
#define DISPLAY_TIMER 3
#define DISPLAY_CONTRAST 4
#define DISPLAY_BRIGHTNESS 5

#define LED_OFF	0
#define LED_ON	1

#define NUM_ICONS 6
#define ICON_TIME 0
#define ICON_DATE 1
#define ICON_TIMER 2
#define ICON_BRIGHTNESS 3
#define ICON_CONTRAST 4
#define ICON_BACK 5

extern "C" void __disable_irq();
extern "C" void __enable_irq();

#pragma GCC diagnostic push
#pragma GCC diagnostic ignored "-Wunused-parameter"
#pragma GCC diagnostic ignored "-Wmissing-declarations"
#pragma GCC diagnostic ignored "-Wreturn-type"
#pragma GCC diagnostic ignored "-Wwrite-strings"



extern volatile timer_ticks_t ticks;
RTC_TimeTypeDef_H24 RTC_TimeStructure;
RTC_DateTypeDef RTC_DateStructure;

IRMP_DATA irmp_data;

// 16kHz
extern "C" void TIM3_IRQHandler() {
	if (TIM_GetITStatus(TIM3, TIM_IT_Update) != RESET) {
		rotenc_irq_process();
		(void) irmp_ISR();
		TIM_ClearITPendingBit(TIM3, TIM_IT_Update);
	}
}

uint16_t lutpwm[LUTPWMSIZE] = { 0 };

void calcPWMLUT() {
	for (int x = 0; x < LUTPWMSIZE; x++) {
		lutpwm[x] = powf(2.0f, (logf((float) SystemCoreClock / 16000.0f) / logf(2.0f)) * ((float) (x + 1)) / LUTPWMSIZE)
				- 1.0f;
	}
}

int switchPressed() {
	return GPIO_ReadInputDataBit(GPIO_SWITCH) == Bit_RESET;
}

int main(int argc, char* argv[]) {
	gpio_init();
	timer_init();
	rotenc_init();
	rtc_init();

	trace_printf("System clock: %u Hz\n", SystemCoreClock);

	timer_start();

	rtc_getTime24(&RTC_TimeStructure);
	rtc_getDate(&RTC_DateStructure);

	usb_init();
	GPIO_SetBits(GPIO_DISC);

	GPIO_ResetBits(GPIO_LCD_RESET);
	timer_sleep(200);
	GPIO_SetBits(GPIO_LCD_RESET);
	timer_sleep(200);

	lcd_init();
	lcd_update();

	UG_Init(&gui, lcd_drawPixel, SCREEN_WIDTH, SCREEN_HEIGHT);
	UG_FillScreen(C_BLACK);
	UG_SetBackcolor(C_BLACK);
	UG_SetForecolor(C_WHITE);
	UG_Update();
	lcd_update();

	calcPWMLUT();
	int16_t pwmval = LUTPWMSIZE - 1;	//500;


// read settings and sanitize them
	pwmval = BKP_ReadBackupRegister(BKP_DR4);
	int16_t contrast = BKP_ReadBackupRegister(BKP_DR5);

	if (contrast<0)
		contrast=0;
	if (contrast>63)
		contrast=63;

	if (pwmval>LUTPWMSIZE-1)
		pwmval=LUTPWMSIZE-1;
	if (pwmval<600)
		pwmval=600;

	TIM3->CCR1 = lutpwm[pwmval]; //3000;

	lcd_setContrast(contrast);
	uint32_t lastticks = 0;

	int mode = ADJUST_NOP;
	int display = DISPLAY_TIME;
	int blink = 0;
	int update = 0;
	int blinktimeout = 0;
	int rotthreshold = 5;
	int rotthreshold_date = 3;
	int rotthreshold_time = 2;
	int rotcnt = 0;
	int sleeptmr = 12;
	int waitswitchrelease = 0;
	int ledstate = LED_ON;
	uint32_t ledonticks = ticks;

	int lpticks = 0;

	const char* icons[NUM_ICONS] = { icon_time, icon_date, icon_timer, icon_brightness, icon_contrast, icon_back };
	int selectedicon = 0;



	while (1) {
		if (usb_isConfigured()) {
			usb_process();
		}

		if (irmp_get_data(&irmp_data)) {
			if (!(irmp_data.flags & IRMP_FLAG_REPETITION)) {
				switch (irmp_data.command) {
				case CMD_QUICK:  // quick
					break;
				case CMD_FADE: // fade
					break;
				case CMD_SLOW:  // slow
					break;
				case CMD_RED:  // red
					break;
				case CMD_GREEN:  // green
					break;
				case CMD_FLASH: // flash
					break;
				case CMD_PLUS1:
				case CMD_PLUS2:
//					event |= EVENT_SHORTPRESS;
					break;
				case CMD_MINUS:
					break;
				case CMD_SET:	// play-button (settings)
//					event |= EVENT_LONGPRESS;
					break;
				}
			}
		}

		if (ticks - lastticks > 500) {
			lastticks = ticks;
			if (mode != ADJUST_TIME && mode != ADJUST_DATE) {
				rtc_checkUpdateDate(&RTC_TimeStructure, &RTC_DateStructure);
				rtc_getTime24(&RTC_TimeStructure);
				rtc_getDate(&RTC_DateStructure);
			}
			if (!blinktimeout)
				blink = 1 - blink;
			else
				blinktimeout--;
			update = 1;
		}

		if (switchPressed()) {
			do {
				if (waitswitchrelease) {
					timer_sleep(250);
					break;
				}
				switch (mode) {
				case ADJUST_NOP:
					if (!lpticks)
						lpticks = ticks;
					break;
				case ADJUST_ICON:
					switch (selectedicon) {
					case ICON_TIME:
						mode = ADJUST_TIME;
						display = DISPLAY_ADJ_TIMEDATE;
						rotcnt = 0;
						update = 1;
						break;
					case ICON_DATE:
						mode = ADJUST_DATE;
						display = DISPLAY_ADJ_TIMEDATE;
						rotcnt = 0;
						update = 1;
						break;
					case ICON_TIMER:
						mode = ADJUST_TIMER;
						display = DISPLAY_TIMER;
						rotcnt = 0;
						update = 1;
						break;
					case ICON_BRIGHTNESS:
						mode = ADJUST_BRIGHTNESS;
						display = DISPLAY_BRIGHTNESS;
						update = 1;
						break;
					case ICON_CONTRAST:
						mode = ADJUST_CONTRAST;
						display = DISPLAY_CONTRAST;
						rotcnt = 0;
						update = 1;
						break;
					case ICON_BACK:
						mode = ADJUST_NOP;
						display = DISPLAY_TIME;
						update = 1;
						break;
					}
					break;
				case ADJUST_TIMER:
					mode = ADJUST_ICON;
					display = DISPLAY_ICON;
					selectedicon = ICON_TIMER;
					update = 1;
					break;
				case ADJUST_BRIGHTNESS:
					mode = ADJUST_ICON;
					display = DISPLAY_ICON;
					selectedicon = ICON_BRIGHTNESS;
					BKP_WriteBackupRegister(BKP_DR4, pwmval);
					update = 1;
					break;
				case ADJUST_CONTRAST:
					mode = ADJUST_ICON;
					display = DISPLAY_ICON;
					selectedicon = ICON_CONTRAST;
					BKP_WriteBackupRegister(BKP_DR5, contrast);
					update = 1;
					break;
				case ADJUST_TIME:
					rtc_setTime24(&RTC_TimeStructure);
					mode = ADJUST_ICON;
					display = DISPLAY_ICON;
					selectedicon = ICON_TIME;
					break;
				case ADJUST_DATE:
					rtc_setDate(&RTC_DateStructure);
					selectedicon = ICON_DATE;
					display = DISPLAY_ICON;
					mode = ADJUST_ICON;
				}
				timer_sleep(250);	// debounce
			} while (0);
		} else {
			lpticks = 0;
			waitswitchrelease = 0;
		}

		if (lpticks && !switchPressed() && (ticks - lpticks) < 500) { // short press
			lpticks = 0;
			ledstate = 1 - ledstate;
			if (ledstate == LED_OFF) {
				TIM3->CCR1 = 0;
			} else {
				ledonticks = ticks;
				TIM3->CCR1 = lutpwm[pwmval];
			}
			// disable LED
		} else if (lpticks && (ticks - lpticks) > 2000) {	// long press
			lpticks = 0;
			if (mode == ADJUST_NOP && display == DISPLAY_TIME) {
				// long press -> goto setup
				mode = ADJUST_ICON;
				display = DISPLAY_ICON;
				rotcnt = 0;
				update = 1;
				waitswitchrelease = 1;
			}
		}

		// sleep timer
		if (sleeptmr && (ticks - ledonticks) > (uint32_t) sleeptmr * 3600 * 1000) // ticks is in ms
				{
			ledstate = LED_OFF;
			TIM3->CCR1 = 0;
		}

		if (ledstate == LED_OFF) {
			mode = ADJUST_NOP;
			display = DISPLAY_TIME;
			update = 1;
		}

		int8_t eval = rotenc_read1();
		eval *= -1; // reverse direction
		if (eval) {
			switch (mode) {
			case ADJUST_CONTRAST:
				rotcnt += eval;
				if (rotcnt > rotthreshold) {
					contrast++;
					rotcnt = 0;
				}
				if (rotcnt < -rotthreshold) {
					contrast--;
					rotcnt = 0;
				}
				if (contrast < 0)
					contrast = 0;
				if (contrast > 63)
					contrast = 63;

				I2C_write(0x80, CMD_SET_VOLUME_FIRST);
				I2C_write(0x80, CMD_SET_VOLUME_SECOND | (contrast & 0x3f));
				break;
			case ADJUST_BRIGHTNESS:
				pwmval += eval;
				if (pwmval < 500)
					pwmval = 500;
				if (pwmval >= LUTPWMSIZE)
					pwmval = LUTPWMSIZE - 1;
				if (pwmval == 500)
					TIM3->CCR1 = 0;
				else
					TIM3->CCR1 = lutpwm[pwmval];
				break;
			case ADJUST_TIME:
				blink = 1; // when adjusting don't blink
				update = 1;
				blinktimeout = 4;
				rotcnt += eval;
				if (rotcnt > rotthreshold_time) {
					rtc_adjustTime(&RTC_TimeStructure, 1);
					rotcnt = 0;
				}
				if (rotcnt < -rotthreshold_time) {
					rtc_adjustTime(&RTC_TimeStructure, -1);
					rotcnt = 0;
				}
				break;
			case ADJUST_DATE:
				blink = 1; // when adjusting don't blink
				update = 1;
				blinktimeout = 4;
				rotcnt += eval;
				if (rotcnt > rotthreshold_date) {
					rtc_adjustDate(&RTC_DateStructure, 1);
					rotcnt = 0;
				}
				if (rotcnt < -rotthreshold_date) {
					rtc_adjustDate(&RTC_DateStructure, -1);
					rotcnt = 0;
				}

				break;
			case ADJUST_TIMER:
				update = 1;
				rotcnt += eval;
				if (rotcnt > rotthreshold) {
					sleeptmr++;
					rotcnt = 0;
				}
				if (rotcnt < -rotthreshold) {
					sleeptmr--;
					rotcnt = 0;
				}
				if (sleeptmr > 24)
					sleeptmr = 24;
				if (sleeptmr < 0)
					sleeptmr = 0;
				break;
			case ADJUST_ICON:
				rotcnt += eval;
				if (rotcnt > rotthreshold) {
					selectedicon++;
					if (selectedicon >= NUM_ICONS)
						selectedicon = NUM_ICONS - 1;
					rotcnt = 0;
				} else if (rotcnt < -rotthreshold) {
					selectedicon--;
					if (selectedicon < 0)
						selectedicon = 0;
					rotcnt = 0;
				}
				update = 1;
				break;
			}
		}

		if (update) {
			update = 0;
			switch (display) {
			case DISPLAY_TIME:
			{
				UG_FillScreen(C_BLACK);
				UG_FontSelect(font);
				int xofs = (RTC_TimeStructure.RTC_Hours < 10) ? 6 : 0;
				lcd_UG_PutStringf(xofs, 2, "%d:", RTC_TimeStructure.RTC_Hours);
				lcd_UG_PutStringf(37 - xofs, 2, "%02d", RTC_TimeStructure.RTC_Minutes);
				int weekday = rtc_weekday(RTC_DateStructure.RTC_Year + 2000, RTC_DateStructure.RTC_Month,
						RTC_DateStructure.RTC_Date);
				char dayNames[][12] = { "Mo", "Di", "Mi", "Do", "Fr", "Sa", "So" };
				lcd_putString5x7f(15, 18, "%s %02d", dayNames[weekday], RTC_DateStructure.RTC_Date);
				break;
			}
			case DISPLAY_ADJ_TIMEDATE:
			{
				UG_FillScreen(C_BLACK);
				if (mode == ADJUST_TIME) {
					UG_PutString(16, 0, "Time");

					UG_FontSelect(font);
					int xofs = (RTC_TimeStructure.RTC_Hours < 10) ? 6 : 0;
					lcd_putString5x7f(xofs, 10, "%d:", RTC_TimeStructure.RTC_Hours);
					lcd_putString5x7f(37 - xofs, 10, "%02d", RTC_TimeStructure.RTC_Minutes);
				}
				if (mode == ADJUST_DATE) {
					UG_PutString(16, 0, "Date");

					lcd_putString5x7f(0, 10, "%02d", RTC_DateStructure.RTC_Date);
					UG_PutString(12, 10, ".");
					lcd_putString5x7f(24 - 6, 10, "%02d", RTC_DateStructure.RTC_Month);
					UG_PutString(36 - 6, 10, ".");
					lcd_putString5x7f(48 - 6 - 6, 10, "%04d", RTC_DateStructure.RTC_Year + 2000);
				}
				break;
			}
			case DISPLAY_TIMER:
			{
				UG_FillScreen(C_BLACK);
				UG_PutString(16, 0, "Timer");
				UG_FontSelect(font);
				if (sleeptmr) {
					lcd_putString5x7f(15, 11, "%2dh", sleeptmr);
				} else
					lcd_putString5x7f(15, 11, "off");
				break;
			}
			case DISPLAY_CONTRAST:
			{
				UG_FillScreen(C_BLACK);
				UG_PutString(0, 0, "Contrast");
				UG_FontSelect(font);
				lcd_putString5x7f(15, 11, "%2d", contrast);
				break;
			}
			case DISPLAY_BRIGHTNESS:
			{
				UG_FillScreen(C_BLACK);
				lcd_putString5x7(0, 0, "Bright");
				UG_FontSelect(font);
				lcd_UG_PutStringf(0, 11, "%4d", pwmval);
				break;
			}
			case DISPLAY_ICON:
			{
				UG_FillScreen(C_BLACK);
				lcd_putIcon(SCREEN_WIDTH - 24, 4, icons[selectedicon]);
				switch (selectedicon) {
				case ICON_TIME:
					lcd_putString5x7(4, 12, "Time");
					break;
				case ICON_DATE:
					lcd_putString5x7(4, 12, "Date");
					break;
				case ICON_TIMER:
					lcd_putString5x7(0, 12, "Timer");
					break;
				case ICON_BRIGHTNESS:
					lcd_putString5x7(0, 12, "Bright");
					break;
				case ICON_CONTRAST:
					lcd_putString5x7(0, 12, "Contr");
					break;
				case ICON_BACK:
					lcd_putString5x7(4, 12, "Back");
					break;

				}
			}

			}
			lcd_update();
		}
	}
	return 0;
}

#pragma GCC diagnostic pop

// ----------------------------------------------------------------------------

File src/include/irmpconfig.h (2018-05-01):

/*---------------------------------------------------------------------------------------------------------------------------------------------------
 * irmpconfig.h
 *
 * DO NOT INCLUDE THIS FILE, WILL BE INCLUDED BY IRMP.H!
 *
 * Copyright (c) 2009-2016 Frank Meyer - frank(at)fli4l.de
 * Extensions for PIC 12F1820 W.Strobl 2014-07-20
 *
 * $Id: irmpconfig.h,v 1.152 2017/02/17 09:13:06 fm Exp $
 *
 * This program is free software; you can redistribute it and/or modify
 * it under the terms of the GNU General Public License as published by
 * the Free Software Foundation; either version 2 of the License, or
 * (at your option) any later version.
 *---------------------------------------------------------------------------------------------------------------------------------------------------
 */

#ifndef _IRMPCONFIG_H_
#define _IRMPCONFIG_H_

#ifndef ARM_STM32
#define ARM_STM32
#endif

#ifndef _IRMP_H_
#  error please include only irmp.h, not irmpconfig.h
#endif

/*---------------------------------------------------------------------------------------------------------------------------------------------------
 * Change F_INTERRUPTS if you change the number of interrupts per second,
 * Normally, F_INTERRUPTS should be in the range from 10000 to 15000, typical is 15000
 * A value above 15000 costs additional program space, absolute maximum value is 20000.
 * On PIC with XC8/C18 Compiler, use 15151 as the correct value.
 *---------------------------------------------------------------------------------------------------------------------------------------------------
 */
#ifndef F_INTERRUPTS
#  define F_INTERRUPTS                          15000   // interrupts per second, min: 10000, max: 20000, typ: 15000
#endif

/*---------------------------------------------------------------------------------------------------------------------------------------------------
 * Change settings from 1 to 0 if you want to disable one or more decoders.
 * This saves program space.
 *
 * 1 enable  decoder
 * 0 disable decoder
 *
 * The standard decoders are enabled per default.
 * Less common protocols are disabled here, you need to enable them manually.
 *
 * If you want to use FDC or RCCAR simultaneous with RC5 protocol, additional program space is required.
 * If you don't need RC5 when using FDC/RCCAR, you should disable RC5.
 * You cannot enable both DENON and RUWIDO, only enable one of them.
 *---------------------------------------------------------------------------------------------------------------------------------------------------
 */

// typical protocols, disable here!             Enable  Remarks                 F_INTERRUPTS            Program Space
#define IRMP_SUPPORT_SIRCS_PROTOCOL             1       // Sony SIRCS           >= 10000                 ~150 bytes
#define IRMP_SUPPORT_NEC_PROTOCOL               1       // NEC + APPLE          >= 10000                 ~300 bytes
#define IRMP_SUPPORT_SAMSUNG_PROTOCOL           1       // Samsung + Samsg32    >= 10000                 ~300 bytes
#define IRMP_SUPPORT_KASEIKYO_PROTOCOL          1       // Kaseikyo             >= 10000                 ~250 bytes

// more protocols, enable here!                 Enable  Remarks                 F_INTERRUPTS            Program Space
#define IRMP_SUPPORT_JVC_PROTOCOL               0       // JVC                  >= 10000                 ~150 bytes
#define IRMP_SUPPORT_NEC16_PROTOCOL             0       // NEC16                >= 10000                 ~100 bytes
#define IRMP_SUPPORT_NEC42_PROTOCOL             0       // NEC42                >= 10000                 ~300 bytes
#define IRMP_SUPPORT_MATSUSHITA_PROTOCOL        0       // Matsushita           >= 10000                  ~50 bytes
#define IRMP_SUPPORT_DENON_PROTOCOL             0       // DENON, Sharp         >= 10000                 ~250 bytes
#define IRMP_SUPPORT_RC5_PROTOCOL               0       // RC5                  >= 10000                 ~250 bytes
#define IRMP_SUPPORT_RC6_PROTOCOL               0       // RC6 & RC6A           >= 10000                 ~250 bytes
#define IRMP_SUPPORT_IR60_PROTOCOL              0       // IR60 (SDA2008)       >= 10000                 ~300 bytes
#define IRMP_SUPPORT_GRUNDIG_PROTOCOL           0       // Grundig              >= 10000                 ~300 bytes
#define IRMP_SUPPORT_SIEMENS_PROTOCOL           0       // Siemens Gigaset      >= 15000                 ~550 bytes
#define IRMP_SUPPORT_NOKIA_PROTOCOL             0       // Nokia                >= 10000                 ~300 bytes
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

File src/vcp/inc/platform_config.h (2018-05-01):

/**
  ******************************************************************************
  * @file    platform_config.h
  * @author  MCD Application Team
  * @version V4.1.0
  * @date    26-May-2017
  * @brief   Evaluation board specific configuration file.
  ******************************************************************************
  * @attention
  *
  * <h2><center>&copy; COPYRIGHT(c) 2017 STMicroelectronics</center></h2>
  *
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
  ******************************************************************************
  */

/* Define to prevent recursive inclusion -------------------------------------*/
#ifndef __PLATFORM_CONFIG_H
#define __PLATFORM_CONFIG_H

//#define USE_STM32L152_EVAL

#include "stm32f10x.h"

#define         ID1          (0x1FFFF7E8)
#define         ID2          (0x1FFFF7EC)
#define         ID3          (0x1FFFF7F0)

  #define USB_DISCONNECT                      GPIOB
  #define USB_DISCONNECT_PIN                  GPIO_Pin_2
  #define RCC_APB2Periph_GPIO_DISCONNECT      RCC_APB2Periph_GPIOB
  #define RCC_APB2Periph_ALLGPIO              (RCC_APB2Periph_GPIOA \
                                               | RCC_APB2Periph_GPIOB \
                                               | RCC_APB2Periph_GPIOC \
                                               | RCC_APB2Periph_GPIOD  )
#if 0
  #define DMAx_CLK                         RCC_AHBPeriph_DMA1

  /* UART defines For STM32F10x (can be ported to any other devices) */
  #define VCP_USART               USART1
  #define VCP_USART_CLK           RCC_APB2Periph_USART1
  #define VCP_USART_APB_CLK       RCC_APB2PeriphClockCmd
  #define VCP_USART_GPIO_CLK      RCC_APB2Periph_GPIOA
  #define VCP_USART_GPIO_APB_CLK  RCC_APB2PeriphClockCmd
  #define VCP_USART_TX_PIN        GPIO_Pin_9
  #define VCP_USART_RX_PIN        GPIO_Pin_10

  /* DMA defines For STM32F10x (can be ported to any other devices) */
  #define VCP_RX_DMA_CHANNEL      DMA1_Channel5
  #define VCP_RX_DMA_IRQ          DMA1_Channel5_IRQn
  #define VCP_RX_DMA_IT_TC        DMA1_IT_TC5
  #define VCP_RX_DMA_IRQHandler   DMA1_Channel5_IRQHandler
  #define VCP_RX_DMA_FLAG_GL      DMA1_FLAG_GL5
  #define VCP_RX_DMA_FLAG_TC      DMA1_FLAG_TC5
#endif
/* The USART RX might be managed either by the CPU (byte by byte)
   or by a DMA, according to VCP_RX_BY_DMA compilation switch */

/* #define VCP_RX_BY_DMA */

#elif defined (USE_STM3210E_EVAL)
  #define USB_DISCONNECT                      GPIOB
  #define USB_DISCONNECT_PIN                  GPIO_Pin_14
  #define RCC_APB2Periph_GPIO_DISCONNECT      RCC_APB2Periph_GPIOB
  #define EVAL_COM1_IRQHandler                USART1_IRQHandler
  #define RCC_APB2Periph_ALLGPIO              (RCC_APB2Periph_GPIOA \
                                               | RCC_APB2Periph_GPIOB \
                                               | RCC_APB2Periph_GPIOC \
                                               | RCC_APB2Periph_GPIOD \
                                               | RCC_APB2Periph_GPIOE )

  #define USARTx_DR_ADDRESS                0x40013804
  #define USARTx_TX_DMA_CHANNEL            DMA1_Channel4
  #define USARTx_TX_DMA_FLAG_TC            DMA1_FLAG_TC4
  #define USARTx_TX_DMA_FLAG_GL            DMA1_FLAG_GL4
  #define USARTx_TX_DMA_IRQ                DMA1_Channel4_IRQn
  #define DMAx_CLK                         RCC_AHBPeriph_DMA1


  /* UART defines For STM32F10x (can be ported to any other devices) */
  #define VCP_USART               USART1
  #define VCP_USART_CLK           RCC_APB2Periph_USART1
  #define VCP_USART_APB_CLK       RCC_APB2PeriphClockCmd
  #define VCP_USART_GPIO_CLK      RCC_APB2Periph_GPIOA
  #define VCP_USART_GPIO_APB_CLK  RCC_APB2PeriphClockCmd
  #define VCP_USART_TX_PIN        GPIO_Pin_9
  #define VCP_USART_RX_PIN        GPIO_Pin_10

  /* DMA defines For STM32F10x (can be ported to any other devices) */
  #define VCP_RX_DMA_CHANNEL      DMA1_Channel5
  #define VCP_RX_DMA_IRQ          DMA1_Channel5_IRQn
  #define VCP_RX_DMA_IT_TC        DMA1_IT_TC5
  #define VCP_RX_DMA_IRQHandler   DMA1_Channel5_IRQHandler
  #define VCP_RX_DMA_FLAG_GL      DMA1_FLAG_GL5
  #define VCP_RX_DMA_FLAG_TC      DMA1_FLAG_TC5


/* Includes ------------------------------------------------------------------*/
#if defined (USE_STM32L152_EVAL)
  //#include "stm32l152_eval.h"

#elif defined (USE_STM32L152D_EVAL)
  #include "stm32l152d_eval.h"

#elif defined (USE_STM3210E_EVAL)
  #include "stm3210e_eval.h"

#elif defined (USE_STM3210B_EVAL)
  #include "stm3210b_eval.h"

#elif defined (USE_STM32373C_EVAL)
 #include "stm32373c_eval.h"

#elif defined (USE_STM32303C_EVAL)
 #include "stm32303c_eval.h"

#elif defined (USE_NUCLEO)
  #include "stm32f30x.h"

#else
 //#error "Missing define: Evaluation board (ie. USE_STM3210E_EVAL)"
#endif
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

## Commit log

2018-05-05 gerber files for pcb
    [beamer1-B.Cu.gbl, beamer1-B.Mask.gbs, beamer1-B.SilkS.gbo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]
2019-12-18 trying to fix the 24hrs bug
    [main.cpp]
